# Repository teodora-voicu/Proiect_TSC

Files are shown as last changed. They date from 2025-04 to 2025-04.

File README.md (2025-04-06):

# OpenBook Reader - Teodora-Andreea Voicu

# Hardware Description

**ESP32-C6-WROOM-1-N8 Microcontroller**
- Serves as the central processing unit, managing all communication and control  
- Supports Wi-Fi, Bluetooth, Zigbee, and Thread for wireless communication

**RTC Module (DS3231SN)**
- Maintains accurate timekeeping and provides time/date information via the I2C protocol

**Flash Memory (W25Q512JVEIQ)**
- Provides high-speed storage using the SPI protocol  
- Used for firmware and data storage

**Battery Management IC (MCP73831)**
- Handles charging of the Li-Ion battery with input from the USB Type-C port  
- GPIO pins monitor charging status and control power management

**Fuel Gauge IC (MAX17048G+T10)**
- Tracks the battery's state of charge and communicates with the microcontroller via I2C

**Environmental Sensor (BME680)**
- Monitors temperature, humidity, pressure, and gas levels  
- Connects via the I2C protocol

**ePaper Display**
- Displays information to the user  
- Interfaced using SPI for fast data updates

**SD Card Socket (J4)**
- Provides expandable storage for data logging or firmware updates  
- Communicates using SPI

**USB Type-C Port (J2)**
- Supplies power to the system and enables communication with external devices  
- Includes D+ and D− lines for USB data transfer

# Detailed ESP32-C6 View

**ESP32-C6 Pin Connections**
- **3V3**: Charging 3.3V  
- **EN**: Reset button  
- **IO0**: Communication with the RTC (alert or timing signals)  
- **IO1**: Communication with the RTC for a stable clock reference  
- **IO2**: Used for SPI (Master In Slave Out)  
- **IO3**: Connects to the display, indicating the display’s busy status  
- **IO4**: Communicates with the SD card  
- **IO5**: Connects to the display, distinguishing between data and command signals  
- **IO6**: Used for SPI communication, synchronizes data transfer  
- **IO7**: Used for SPI (Master Out Slave In)  
- **IO8**:  
- **IO9**: Boot button  
- **IO10**: Connects to the display, selects the display for communication  
- **IO11**: Selects the flash memory for communication  
- **IO12**: D+ for USB connection  
- **IO13**: D− for USB connection  
- **IO15**: Change button  
- **TXD0 / GPIO16**: Used for UART debugging  
- **RXD0 / GPIO17**: Used for UART debugging  
- **IO18**: Resets the RTC  
- **IO19**: Power pin for I2C communication  
- **IO20**: Power supply for the display  
- **IO21**: I2C data pin  
- **IO22**: I2C clock pin  
- **IO23**: Resets the display  
- **GND**: Connected to ground

## BOM

| **Piece Name** | **Piece Type (Optional)** | **Link** |
|---|---|---|
| ESP32-CAP C0402 | C | https://componentsearchengine.com/part-view/CC0402MRX5R5BB106/YAGEO |
| ADAFRUIT_CHIP-LED0603 | LED | https://www.snapeda.com/parts/KP-1608SURCK/Kingbright/view-part/?ref=search&t=LED%200603 |
| 112ATAARR03 | microSD | https://www.snapeda.com/parts/112A-TAAR-R03/Attend/view-part/ |
| 744043680 | L | https://eu.mouser.com/ProductDetail/Wurth-Elektronik/744043680?qs=PGXP4M47uW6VkZq%252BkzjrHA%3D%3D |
| BD5229G-TR | Voltage Detector | https://www.snapeda.com/parts/BD5229G-TR/Rohm/view-part/?ref=search&t=BD5229G-TR |
| BUTTON_CUSYOMV1 | Button | https://www.snapeda.com/search/?q=EVQP7L01P&search-type=parts |
| CPH3225A | C | https://www.snapeda.com/parts/CPH3225A/Seiko/view-part/ |
| DS3231SN# | I²C-Integrated RTC/TCXO/Crystal | https://www.snapeda.com/parts/DS3231SN%23/Analog%20Devices/view-part/?ref=search&t=DS3231SN%23 |
| ESP32-C6-WROOM-1-N8 | ESP32 | https://www.snapeda.com/parts/ESP32-C6-WROOM-1-N8/Espressif%20Systems/view-part/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 |
| ESP VARSISTOR | Varsistor (B72520T0350K062) | https://ro.mouser.com/ProductDetail/EPCOS-TDK/B72520T0350K062?qs=dEfas%2FXlABIszF52uu7vrg%3D%3D |
| ESP32_WROVER_AVX---SD0805S020S1R0 |  DIODE SCHOTTKY | https://componentsearchengine.com/part-view/SD0805S020S1R0/Kyocera%20AVX |
| ESP32_WROVER_BME680_BME680 | Env Senzor | https://www.snapeda.com/parts/BME680/Bosch%20Sensortec/view-part/?ref=search&t=bme680 |
| ESP32_WROVER_EAGLE-LTSPICE_R | R | https://componentsearchengine.com/part-view/R0402%201%25%20100%20K%20(RC0402FR-07100KL)/YAGEO |
| ESP32_WROVER_SPARKFUN-DISCRETESEMI_MOSFET_PCH | T DMG2305UX-7 | https://componentsearchengine.com/part-view/DMG2305UX-7/Diodes%20Incorporated |
| ESP32_WROVER_SPARKFUN-IC-POWER_MCP73831 | TINY INTEGRATED LI-ION/LI-POLY CHARGE MGNT CONTROLLER | https://componentsearchengine.com/part-view/MCP73831T-2ACI%2FOT/Microchip |
| FH34SRJ-24S-0.5SH_99_ | FH34SRJ-24S-0.5SH(99) | https://componentsearchengine.com/part-view/FH34SRJ-24S-0.5SH(99)/Hirose |
| MAX17048G+T10 |  Cell Fuel Gauge with ModelGauge | https://www.snapeda.com/parts/MAX17048G+T10/Analog%20Devices/view-part/ |
| MBR0530 |  Diode Schottky | https://www.snapeda.com/parts/MBR0530/Onsemi/view-part/ |
| PGB1010603MR |  Ipp Tvs Diode Surface Mount 0603 | https://www.snapeda.com/parts/PGB1010603MR/Littelfuse/view-part/ |
| QWIIC_CONNECTOR | PRT-14417 QWIIC_CONNECTOR | https://www.snapeda.com/parts/PRT-14417/SparkFun/view-part/ |
| RCL_CPOL-EU | C pol | https://grabcad.com/library/tantalum-smd-capacitor-type-b-3528-1 |
| SAMACSYS_PARTS_USB4110-GF-A | USB4110-GF-A | https://www.snapeda.com/parts/USB4110-GF-A./Global%20Connector%20Technology/view-part/ |
| SJ | Jumper-SolderPasteJumper3way | https://grabcad.com/library/solder-jumpers-1 |
| TP | Test-Pad | - |
| SI1308EDL-T1-GE3 |  MOSFET Transistor | https://www.snapeda.com/parts/SI1308EDL-T1-GE3/Vishay/view-part/ |
| USBLC6-2SC6Y |  Ipp Tvs Diode Surface Mount | https://www.snapeda.com/parts/USBLC6-2SC6Y/STMicroelectronics/view-part/?ref=dk&t=USBLC6-2SC6Y&con_ref=None |
| W25Q512JVEIQ | FLASH - NOR Memory | https://www.snapeda.com/parts/W25Q512JVEIQ/Winbond%20Electronics/view-part/?ref=search&t=W25Q512JVEIQ |
| XC6220A331MR-G | Voltage Regulator | https://ro.mouser.com/ProductDetail/Torex-Semiconductor/XC6220A331MR-G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 |

# Block Diagram
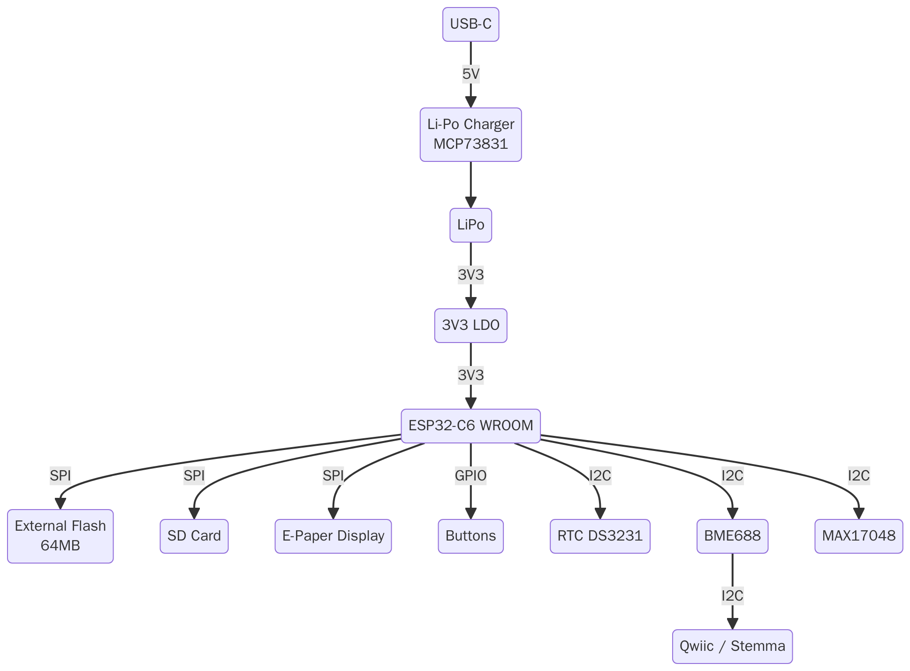
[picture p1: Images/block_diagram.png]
Block Diagram


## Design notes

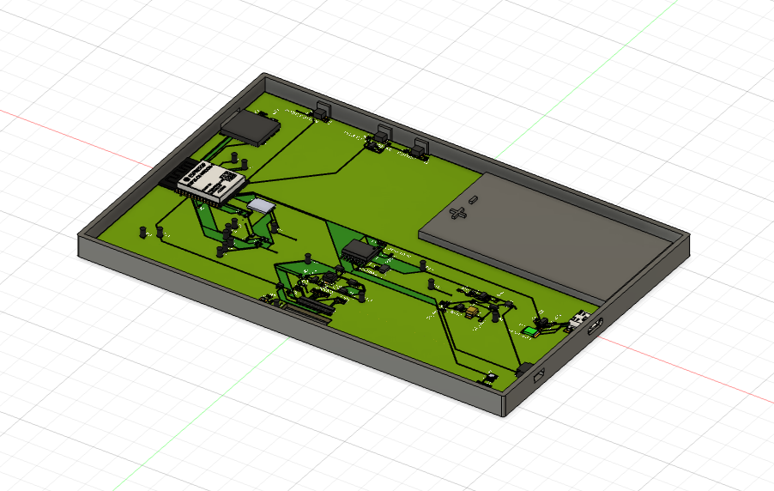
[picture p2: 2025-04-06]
Images/full_home_no_lid.png

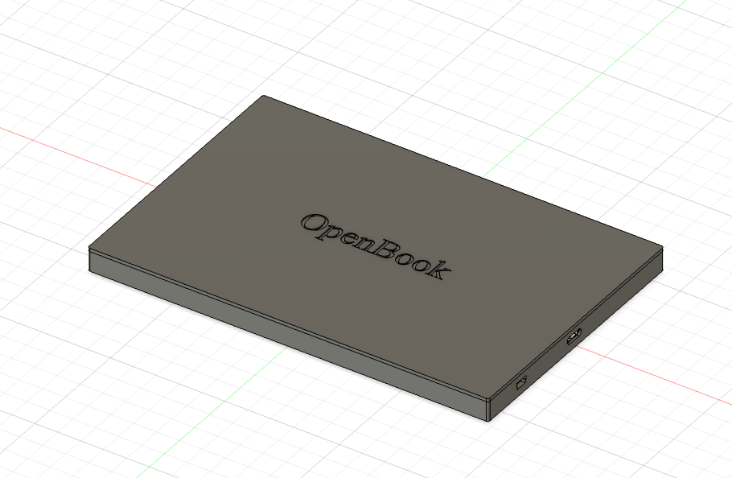
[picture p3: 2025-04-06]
Images/full_home_lid.png

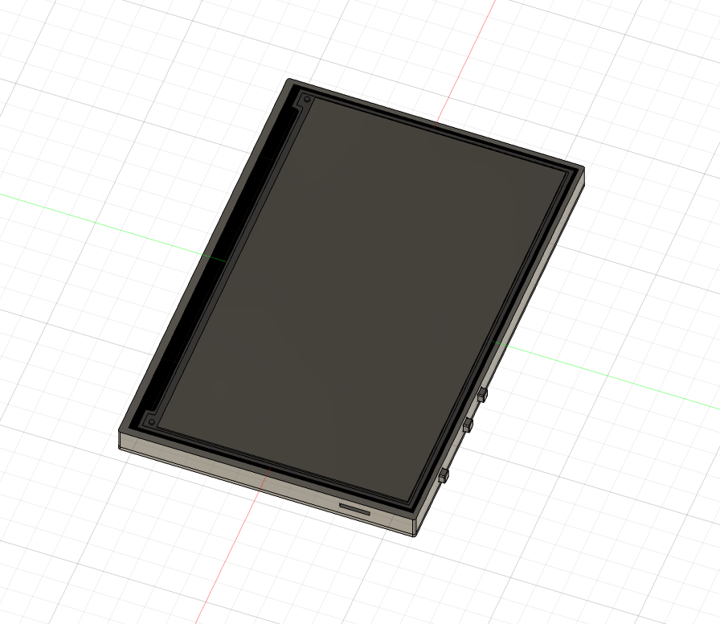
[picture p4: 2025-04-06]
Images/full_top_lid.png

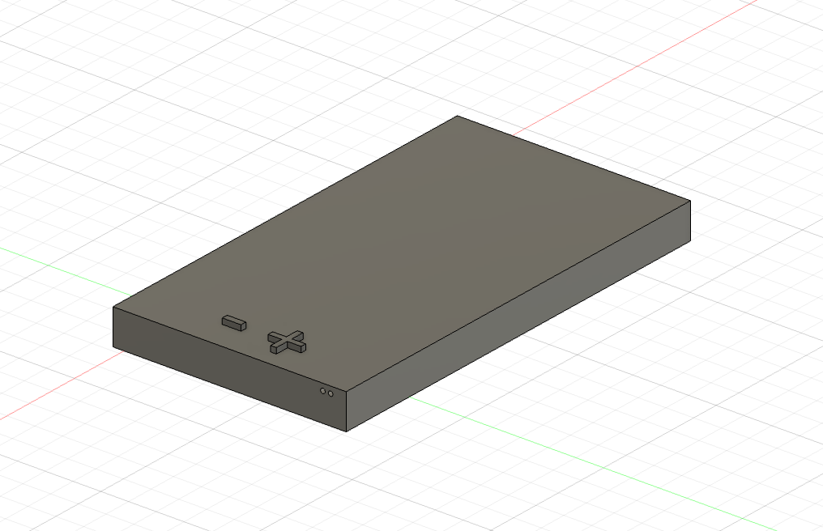
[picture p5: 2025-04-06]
Images/battery.png

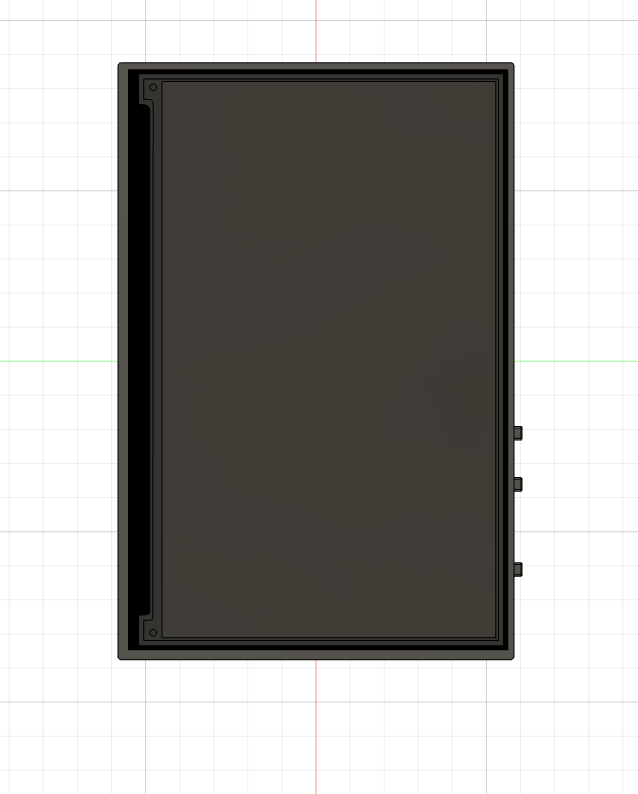
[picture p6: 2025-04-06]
Images/full_top.png

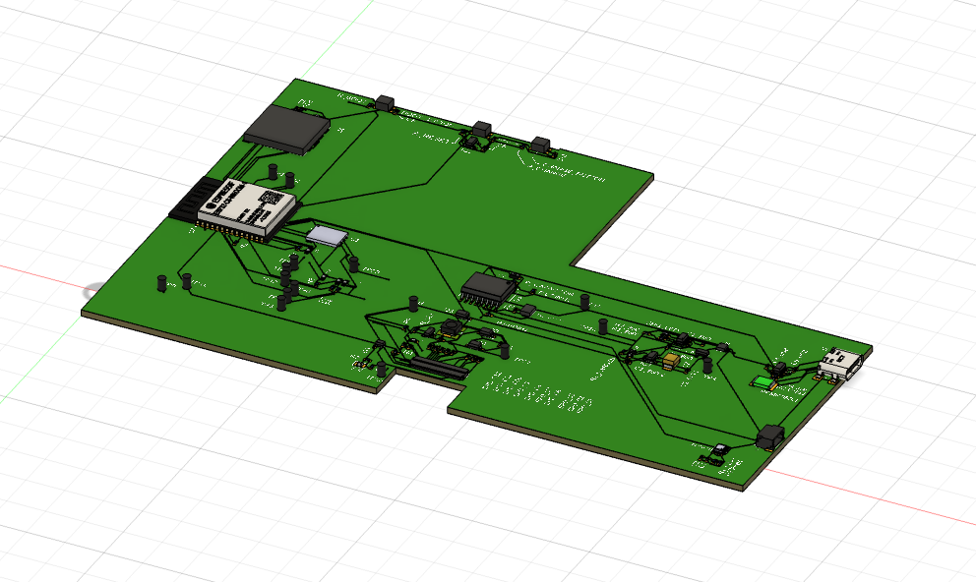
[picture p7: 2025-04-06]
Images/pcb.png

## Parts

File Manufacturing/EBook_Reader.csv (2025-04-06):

Qty | Value | Device | Package | Parts | Description | ARROW_PART_NUMBER | ARROW_PRICE-STOCK | AVAILABILITY | CENTROID_NOT_SPECIFIED | CHECK_PRICES | COPYRIGHT | DATASHEET | DESCRIPTION | DIGIKEY_DESCRIPTION | DIGIKEY_PART_NUMBER | HEIGHT | LEAD_FREE | MANUFACTURER_NAME | MANUFACTURER_PART_NUMBER | MF | MFR_NAME | MOUSER_PART_NUMBER | MOUSER_PRICE-STOCK | MOUSER_TESTING_PART_NUMBER | MOUSER_TESTING_PRICE-STOCK | MP | MPN | PACKAGE | POPULARITY | PREFIX | PRICE | PROD_ID | PURCHASE-URL | ROHS | SNAPEDA_LINK | SPICEMODEL | SPICEPREFIX | TEMPERATURE_RANGE_HIGH | TEMPERATURE_RANGE_LOW | TP_SIGNAL_NAME | VALUE
1 |  | ADAFRUIT_LEDCHIP-LED0603 | ADAFRUIT_CHIP-LED0603 | CHG_LED | LED
1 |  | SJ | SJ | SJ1 | SMD solder JUMPER |  |  |  |  |  |  |  |  |  |  |  |  |  |  |  |  |  |  |  |  |  |  |  | 3
1 | 0.47 | ESP32_WROVER_EAGLE-LTSPICE_RR0402 | ESP32_WROVER_EAGLE-LTSPICE_R0402 | R3 | RESISTOR, European symbol |  |  |  |  |  |  |  |  |  |  |  |  |  |  |  |  |  |  |  |  |  |  |  |  |  |  |  |  |  |  | NONE | R
1 | 100K | ESP32_WROVER_EAGLE-LTSPICE_RR0402 | ESP32_WROVER_EAGLE-LTSPICE_R0402 | R1_PWRUSB | RESISTOR, European symbol |  |  |  |  |  |  |  |  |  |  |  |  |  |  |  |  |  |  |  |  |  |  |  |  |  |  |  |  |  |  | NONE | R
8 | 100nF | ESP32_WROVER_EAGLE-LTSPICE_CC0402 | ESP32_WROVER_EAGLE-LTSPICE_C0402 | C1, C2, C4_USB, C6, C8, C9, C10, C_DELAY | CAPACITOR, European symbol |  |  |  |  |  |  |  |  |  |  |  |  |  |  |  |  |  |  |  |  |  |  |  |  |  |  |  |  |  |  | NONE | C
1 | 100uF TANT | RCL_CPOL-EUCT3528 | RCL_CT3528 | C3 | POLARIZED CAPACITOR, European symbol |  |  |  |  |  |  |  |  |  |  |  |  |  |  |  |  |  |  |  |  |  |  |  | 0 |  |  |  |  |  |  |  | C
14 | 10K | ESP32_WROVER_EAGLE-LTSPICE_RR0402 | ESP32_WROVER_EAGLE-LTSPICE_R0402 | R1, R1-PINH1, R1_PINH, R2-PINH, R2-PINH1, R4, R5, R6, R7, R8, R9, R10, R_BOOT, R_CHANGE | RESISTOR, European symbol |  |  |  |  |  |  |  |  |  |  |  |  |  |  |  |  |  |  |  |  |  |  |  |  |  |  |  |  |  |  | NONE | R
2 | 10k | ESP32_WROVER_EAGLE-LTSPICE_RR0402 | ESP32_WROVER_EAGLE-LTSPICE_R0402 | R_CL1, R_RESET | RESISTOR, European symbol |  |  |  |  |  |  |  |  |  |  |  |  |  |  |  |  |  |  |  |  |  |  |  |  |  |  |  |  |  |  | NONE | R
1 | 10uF | ESP32_WROVER_EAGLE-LTSPICE_CC0402 | ESP32_WROVER_EAGLE-LTSPICE_C0402 | C7 | CAPACITOR, European symbol |  |  |  |  |  |  |  |  |  |  |  |  |  |  |  |  |  |  |  |  |  |  |  |  |  |  |  |  |  |  | NONE | C
1 | 112A-TAAR-R03_ATTEND | 112A-TAAR-R03_ATTEND | 112ATAARR03ATTEND | J4 | Micro SD Card Socket, Push-Push Type, Top Mount, SMT, H=1.83mm, 10u |  |  |  |  |  |  |  | Micro SD Card Socket | Push-Push Type | Top Mount | SMT | H=1.83mm | 10u |  |  | 1.9mm |  | ATTEND | 112A-TAAR-R03 ATTEND
1 | 15 | ESP32_WROVER_EAGLE-LTSPICE_RR0402 | ESP32_WROVER_EAGLE-LTSPICE_R0402 | R_CAPACITOR | RESISTOR, European symbol |  |  |  |  |  |  |  |  |  |  |  |  |  |  |  |  |  |  |  |  |  |  |  |  |  |  |  |  |  |  | NONE | R
1 | 1uF | ESP32_WROVER_EAGLE-LTSPICE_CC0402 | ESP32_WROVER_EAGLE-LTSPICE_C0402 | C5 | CAPACITOR, European symbol |  |  |  |  |  |  |  |  |  |  |  |  |  |  |  |  |  |  |  |  |  |  |  |  |  |  |  |  |  |  | NONE | C
10 | 1uF/50V | ESP32_WROVER_EAGLE-LTSPICE_CC0402 | ESP32_WROVER_EAGLE-LTSPICE_C0402 | EPD_C1, EPD_C2, EPD_C5, EPD_C6, EPD_C7, EPD_C8, EPD_C9, EPD_C10, EPD_C11, EPD_C12 | CAPACITOR, European symbol |  |  |  |  |  |  |  |  |  |  |  |  |  |  |  |  |  |  |  |  |  |  |  |  |  |  |  |  |  |  | NONE | C
1 | 2.2 | ESP32_WROVER_EAGLE-LTSPICE_RR0402 | ESP32_WROVER_EAGLE-LTSPICE_R0402 | R2 | RESISTOR, European symbol |  |  |  |  |  |  |  |  |  |  |  |  |  |  |  |  |  |  |  |  |  |  |  |  |  |  |  |  |  |  | NONE | R
1 | 200 | ESP32_WROVER_EAGLE-LTSPICE_RR0402 | ESP32_WROVER_EAGLE-LTSPICE_R0402 | R1_BAT | RESISTOR, European symbol |  |  |  |  |  |  |  |  |  |  |  |  |  |  |  |  |  |  |  |  |  |  |  |  |  |  |  |  |  |  | NONE | R
2 | 20V/4.2A/52mΩ/1.4W | ESP32_WROVER_SPARKFUN-DISCRETESEMI_MOSFET_PCH-DMG2305UX-7 | ESP32_WROVER_SPARKFUN-DISCRETESEMI_SOT23-3 | Q1, Q2 | P-channel MOSFETs |  |  |  |  |  |  |  |  |  |  |  |  |  |  |  |  |  |  |  |  |  |  |  |  |  |  | TRAN-14388 |  |  |  |  |  |  |  |  | 20V/4.2A/52mΩ/1.4W
1 | 2K | ESP32_WROVER_EAGLE-LTSPICE_RR0402 | ESP32_WROVER_EAGLE-LTSPICE_R0402 | R2_BAT | RESISTOR, European symbol |  |  |  |  |  |  |  |  |  |  |  |  |  |  |  |  |  |  |  |  |  |  |  |  |  |  |  |  |  |  | NONE | R
5 | 4.7uF | ESP32_WROVER_EAGLE-LTSPICE_CC0402 | ESP32_WROVER_EAGLE-LTSPICE_C0402 | C1_BAT, C1_BAT1, C1_BAT2, C2_BAT, C5_USB | CAPACITOR, European symbol |  |  |  |  |  |  |  |  |  |  |  |  |  |  |  |  |  |  |  |  |  |  |  |  |  |  |  |  |  |  | NONE | C
1 | 4.7uF/25V | ESP32_WROVER_EAGLE-LTSPICE_CC0402 | ESP32_WROVER_EAGLE-LTSPICE_C0402 | C4 | CAPACITOR, European symbol |  |  |  |  |  |  |  |  |  |  |  |  |  |  |  |  |  |  |  |  |  |  |  |  |  |  |  |  |  |  | NONE | C
2 | 5k1 | ESP32_WROVER_EAGLE-LTSPICE_RR0402 | ESP32_WROVER_EAGLE-LTSPICE_R0402 | R2-USB, R2-USB1 | RESISTOR, European symbol |  |  |  |  |  |  |  |  |  |  |  |  |  |  |  |  |  |  |  |  |  |  |  |  |  |  |  |  |  |  | NONE | R
1 | 68uH | 744043680IND_4828-WE-TPC_WRE | IND_4828-WE-TPC_WRE | L1 |  |  |  |  |  |  | Copyright (C) 2024 Ultra Librarian. All rights reserved. |  |  |  |  |  |  |  | 744043680 |  | Wurth Electronics
1 | BD5229G-TR | BD5229G-TR | SOT95P280X125-5N | IC1 | Voltage Detector with Adjustable Delay Time: CMOS processes are utilized to develop high precision, low current consumption CMOS reset ICs that allow arbitrary setting of the delay time. The extensive lineup includes both Nch Open Drain and CMOS output types in a wide range of detection voltages (from 2.3V to 6.0V, in 0.1V steps), enabling selection of the ideal solution based on customer requirements. In addition, the entire series is of course both lead-free and RoHS-compliant. |  |  |  |  |  |  |  | Voltage Detector with Adjustable Delay Time: CMOS processes are utilized to develop high precision | low current consumption CMOS reset ICs that allow arbitrary setting of the delay time. The extensive lineup includes both Nch Open Drain and CMOS output types in a wide range of detection voltages (from 2.3V to 6.0V | in 0.1V steps) | enabling selection of the ideal solution based on customer requirements. In addition | the entire series is of course both lead-free and RoHS-compliant. |  |  | 1.25mm |  | ROHM Semiconductor | BD5229G-TR |  |  | 755-BD5229G-TR | https://www.mouser.co.uk/ProductDetail/ROHM-Semiconductor/BD5229G-TR?qs=4kLU8WoGk0vvnhrrYwdszw%3D%3D
3 | BUTTON_CUSYOMV1 | BUTTON_CUSYOMV1 | MYBUTTON | BOOT_BUTTON, CHANGE_BUTTON, RESET_BUTTON
1 | CPH3225A | CPH3225A | CAPCP3225X100N | C10_SUPERCAP | Cap 0.011F 3.3V 1210 Flat Check availability |  |  | Not in stock |  | https://www.snapeda.com/parts/CPH3225A/Seiko+Instruments/view-part/?ref=eda |  |  | 11 mF (EDLC) Supercapacitor 3.3 V 1210 (3225 Metric) - - |  |  |  |  |  |  | Seiko Instruments |  |  |  |  |  | CPH3225A |  | 1210 Seiko |  |  | None |  | https://www.snapeda.com/api/url_track_click_mouser/?unipart_id=562593&manufacturer=Seiko Instruments&part_name=CPH3225A&search_term=None |  | https://www.snapeda.com/parts/CPH3225A/Seiko+Instruments/view-part/?ref=snap
1 | DS3231SN# | DS3231SN# | SOIC127P1032X265-16N | U3 | Real Time Clock Serial 16-Pin SOIC W T/R Check availability |  |  | In Stock |  | https://www.snapeda.com/parts/DS3231SN%23/Analog+Devices/view-part/?ref=eda |  |  | Extremely Accurate I²C-Integrated RTC/TCXO/Crystal |  |  |  |  |  |  | Analog Devices |  |  |  |  |  | DS3231SN# |  | SOIC-16 Maxim |  |  | None |  | https://www.snapeda.com/api/url_track_click_mouser/?unipart_id=99048&manufacturer=Analog Devices&part_name=DS3231SN#&search_term=None |  | https://www.snapeda.com/parts/DS3231SN%23/Analog+Devices/view-part/?ref=snap
1 | ESP32-C6-WROOM-1-N8 | ESP32-C6-WROOM-1-N8 | XCVR_ESP32-C6-WROOM-1-N8 | U2 | Check availability |  |  | In Stock |  | https://www.snapeda.com/parts/ESP32-C6-WROOM-1-N8/Espressif+Systems/view-part/?ref=eda |  |  | Multiprotocol Modules ESP32-C6 module | Wi-Fi 6 in 2.4 GHz band | Bluetooth 5 | Zigbee 3.0 and Thread. ESP34-WROOM Compatible - ENGINEERING SAMPLE |  |  |  |  |  |  | Espressif Systems |  |  |  |  |  | ESP32-C6-WROOM-1-N8 |  | None |  |  | None |  |  |  | https://www.snapeda.com/parts/ESP32-C6-WROOM-1-N8/Espressif+Systems/view-part/?ref=snap
1 | ESP32C6_VARISTORCN1812 | ESP32C6_VARISTORCN1812 | ESP32C6_VARISTOR_CT/CN1812 | PFMF.050.1 | VARISTOR |  |  |  |  |  |  |  |  |  |  |  |  |  |  |  |  |  |  |  |  |  |  |  | 0
2 | ESP32_WROVER_AVX---SD0805S020S1R0_AVX_SD0805S020S1R0_0_0AVX_SD0805S020S1R0_0_0 | ESP32_WROVER_AVX---SD0805S020S1R0_AVX_SD0805S020S1R0_0_0AVX_SD0805S020S1R0_0_0 | ESP32_WROVER_AVX---SD0805S020S1R0_AVX_SD0805S020S1R0_0 | D2, D7 | Schottky Barrier Rectifier Diode |  |  |  | No |  |  | http://datasheets.avx.com/schottky.pdf |  | DIODE SCHOTTKY 20V 1A 0805 | 478-7800-1-ND |  | yes |  |  | AVX |  | 581-SD0805S020S1R0 |  |  |  |  |  | 0805 (2012 metric) |  | D |  |  |  | yes |  |  |  | +125°C | -55°C
1 | ESP32_WROVER_BME680_BME680 | ESP32_WROVER_BME680_BME680 | ESP32_WROVER_BME680_PSON80P300X300X100-8N | SENSOR2 | Integrated Environmental Unit |  |  | Unavailable |  |  |  |  | Integrated Environmental Unit |  |  |  |  |  |  | Bosch Sensortec |  |  |  |  |  | BME680 |  | LGA-8 Bosch Tools |  |  | None
1 | ESP32_WROVER_SPARKFUN-IC-POWER_MCP73831 | ESP32_WROVER_SPARKFUN-IC-POWER_MCP73831 | ESP32_WROVER_SPARKFUN-IC-POWER_SOT23-5 | MCP73831 | MCP73831T Li-Ion, Li-Pol Controller |  |  |  |  |  |  |  |  |  |  |  |  |  |  |  |  |  |  |  |  |  |  |  |  |  |  | IC-09995
1 | FH34SRJ-24S-0.5SH_99_ | FH34SRJ-24S-0.5SH_99_ | FH34SRJ24S05SH99 | J1 | (0.50mm) Surface Mount, Right Angle |  |  |  |  |  |  |  | 24 Position FFC | FPC Connector Contacts | (0.50mm) Surface Mount | Right Angle |  |  | 1.1mm |  | Hirose | FH34SRJ-24S-0.5SH(99) |  |  | 798-FH34SRJ24S05SH99 | https://www.mouser.co.uk/ProductDetail/Hirose-Connector/FH34SRJ-24S-0.5SH99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
1 | MAX17048G+T10 | MAX17048G+T10 | SON50P200X200X80-9N | U4 | Check availability |  |  | In Stock |  | https://www.snapeda.com/parts/MAX17048G+T10/Analog+Devices/view-part/?ref=eda |  |  | 3µA 1-Cell/2-Cell Fuel Gauge with ModelGauge |  |  |  |  |  |  | Analog Devices |  |  |  |  |  | MAX17048G+T10 |  | TDFN-8 Maxim |  |  | None |  | https://www.snapeda.com/api/url_track_click_mouser/?unipart_id=329239&manufacturer=Analog Devices&part_name=MAX17048G+T10&search_term=None |  | https://www.snapeda.com/parts/MAX17048G+T10/Analog+Devices/view-part/?ref=snap
3 | MBR0530 | MBR0530 | SOD3716X135N | D3, D4, D5 | ON SEMICONDUCTOR - MBR0530 - DIODE, SCHOTTKY, 0.5A, 30V, SOD-123 |  |  | In Stock |  | https://www.snapeda.com/parts/MBR0530/Onsemi/view-part/?ref=eda |  |  | Diode Schottky 30 V 500mA Surface Mount SOD-123 |  |  |  |  |  |  | ON Semiconductor |  |  |  |  |  | MBR0530 |  | SOD-123-2 ON Semiconductor |  |  | None |  | https://www.snapeda.com/api/url_track_click_mouser/?unipart_id=179458&manufacturer=ON Semiconductor&part_name=MBR0530&search_term=None |  | https://www.snapeda.com/parts/MBR0530/Onsemi/view-part/?ref=snap
6 | PGB1010603MR | PGB1010603MR | DIOC1608X36N | D6, D8, D9, D10, D11, D12 | Check availability |  |  | In Stock |  | https://www.snapeda.com/parts/PGB1010603MR/Littelfuse/view-part/?ref=eda |  |  | 150V (Typ) Clamp - Ipp Tvs Diode Surface Mount 0603 (1608 Metric) |  |  |  |  |  |  | Littelfuse Inc. |  |  |  |  |  | PGB1010603MR |  | 0603 Littelfuse Inc. |  |  | None |  | https://www.snapeda.com/api/url_track_click_mouser/?unipart_id=5659453&manufacturer=Littelfuse Inc.&part_name=PGB1010603MR&search_term=None |  | https://www.snapeda.com/parts/PGB1010603MR/Littelfuse/view-part/?ref=snap
1 | QWIIC_RIGHT_ANGLE | QWIIC_CONNECTORJS-1MM | JST04_1MM_RA | J3 | SparkFun I2C Standard Qwiic Connector |  |  |  |  |  |  |  |  |  |  |  |  |  |  |  |  |  |  |  |  |  |  |  |  |  |  | CONN-13694 |  |  |  |  |  |  |  |  | QWIIC_RIGHT_ANGLE
1 | SAMACSYS_PARTS_USB4110-GF-A | SAMACSYS_PARTS_USB4110-GF-A | SAMACSYS_PARTS_USB4110GFA | J2 | CONN USB 2.0 TYPE-C R/A SMT |  |  |  |  |  |  |  | CONN USB 2.0 TYPE-C R/A SMT |  |  | 3.26mm |  | GCT (GLOBAL CONNECTOR TECHNOLOGY) | USB4110-GF-A |  |  | 640-USB4110-GF-A | https://www.mouser.co.uk/ProductDetail/GCT/USB4110-GF-A?qs=KUoIvG%2F9IlYiZvIXQjyJeA%3D%3D
1 | SI1308EDL-T1-GE3 | SI1308EDL-T1-GE3 | SOT65P210X110-3N | Q3 | MOSFET N-Ch 30V 1.5A TrenchFET SC70 Vishay Si1308EDL-T1-GE3 N-channel MOSFET Transistor, 1.5 A, 30 V, 3-Pin SC-70 |  |  | In Stock |  | https://www.snapeda.com/parts/SI1308EDL-T1-GE3/Vishay+Siliconix/view-part/?ref=eda |  |  | Si1308EDL-T1-GE3 N-channel MOSFET Transistor | 1.5 A | 30 V | 3-Pin SC-70 | Siliconix / Vishay SI1308EDL-T1-GE3 |  |  |  |  |  |  | Vishay Siliconix |  |  |  |  |  | SI1308EDL-T1-GE3 |  | SOT-323 Vishay Semiconductor |  |  | None |  | https://www.snapeda.com/api/url_track_click_mouser/?unipart_id=274603&manufacturer=Vishay Siliconix&part_name=SI1308EDL-T1-GE3&search_term=None |  | https://www.snapeda.com/parts/SI1308EDL-T1-GE3/Vishay+Siliconix/view-part/?ref=snap
17 | TPTP20R | TPTP20R | TP20R | TP1, TP2, TP3, TP4, TP5, TP6, TP7, TP8, TP9, TP10, TP11, TP12, TP13, TP14, TP15, TP16, TP17 | Test pad |  |  |  |  |  |  |  |  |  |  |  |  |  |  |  |  |  |  |  |  |  |  |  | 2
1 | USBLC6-2SC6Y | USBLC6-2SC6Y | SOT95P280X145-6N | D1 | Low Cap. ESD Protection Auto SOT-23-6 STMicroelectronics USBLC6-2SC6Y, Dual Uni-Directional TVS Diode Array, 6-Pin SOT-23 |  |  | In Stock |  | https://www.snapeda.com/parts/USBLC6-2SC6Y/STMicroelectronics/view-part/?ref=eda |  |  | 17V Clamp 5A (8/20µs) Ipp Tvs Diode Surface Mount SOT-23-6 |  |  |  |  |  |  | STMicroelectronics |  |  |  |  |  | USBLC6-2SC6Y |  | SOT-23-6 STMicroelectronics |  |  | None |  |  |  | https://www.snapeda.com/parts/USBLC6-2SC6Y/STMicroelectronics/view-part/?ref=snap
1 | W25Q512JVEIQ | W25Q512JVEIQ | SON127P600X800X80-9N | U1 | Check availability |  |  | In Stock |  | https://www.snapeda.com/parts/W25Q512JVEIQ/Winbond+Electronics/view-part/?ref=eda |  |  | FLASH - NOR Memory IC 512Mb (64M x 8) SPI - Quad I/O 133 MHz 8-WSON (8x6) |  |  |  |  |  |  | Winbond Electronics |  |  |  |  |  | W25Q512JVEIQ |  | Package |  |  | None |  |  |  | https://www.snapeda.com/parts/W25Q512JVEIQ/Winbond+Electronics/view-part/?ref=snap
1 | XC6220A331MR-G | XC6220A331MR-G | SOT95P280X120-5N | IC4 | LDO Voltage Regulators |  |  |  |  |  |  |  | LDO Voltage Regulators |  |  | 1.2mm |  | Torex | XC6220A331MR-G |  |  | 865-XC6220A331MR-G | https://www.mouser.co.uk/ProductDetail/Torex-Semiconductor/XC6220A331MR-G?qs=AsjdqWjXhJ8ZSWznL1J0gg%3D%3D

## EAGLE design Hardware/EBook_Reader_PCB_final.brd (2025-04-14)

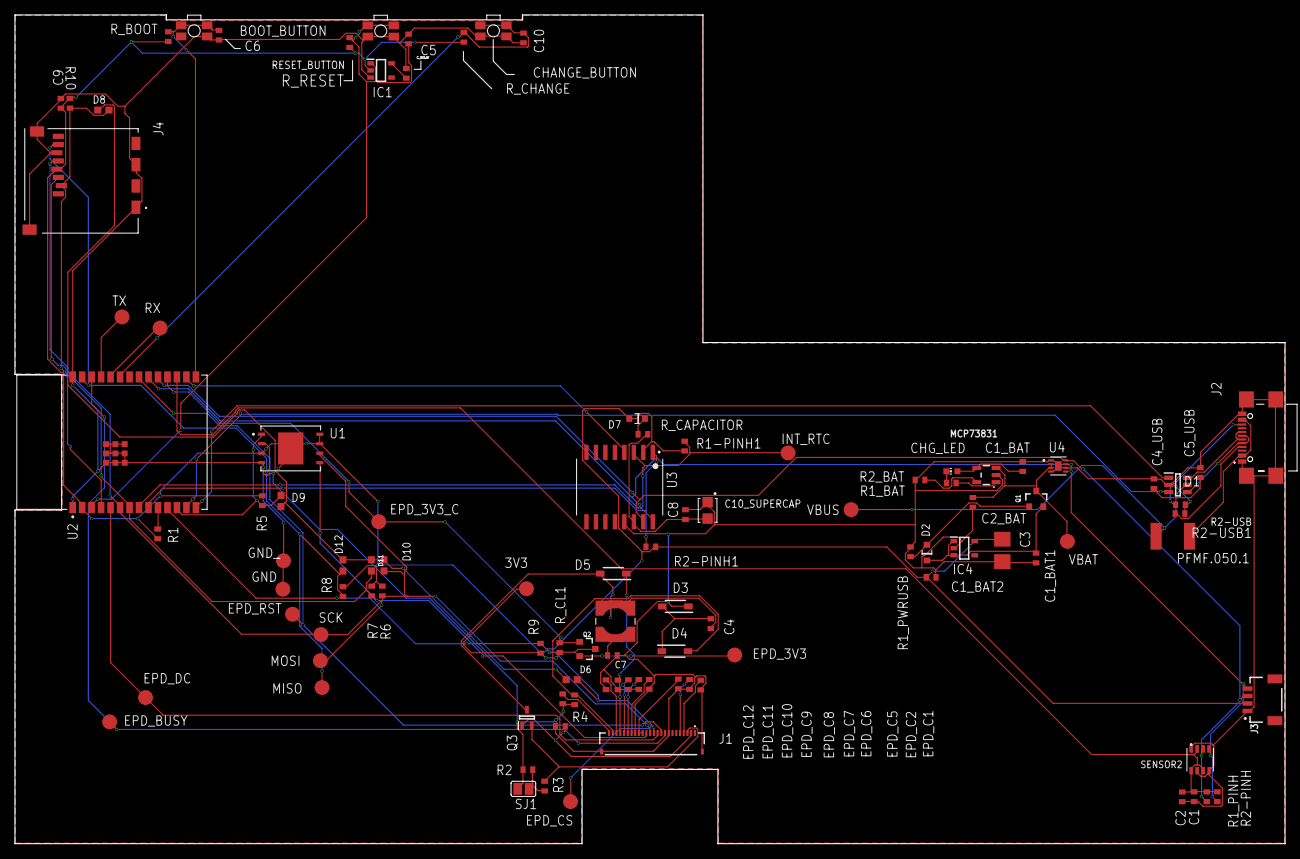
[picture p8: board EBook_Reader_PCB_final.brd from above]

Board: 2 copper layers, 170.2 x 111.1 mm, 103 parts (0 on the bottom side), 61 nets.

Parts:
3V3: TPTP20R; TP20R
BOOT_BUTTON: BUTTON_CUSYOMV1; MYBUTTON
C1, C2, C4_USB, C6, C8, C9, C10: 100nF; ESP32_WROVER_EAGLE-LTSPICE_C0402
C1_BAT, C1_BAT1, C1_BAT2, C2_BAT, C5_USB: 4.7uF; ESP32_WROVER_EAGLE-LTSPICE_C0402
C3: 100uF TANT; RCL_CT3528
C4: 4.7uF/25V; ESP32_WROVER_EAGLE-LTSPICE_C0402
C5: 1uF; ESP32_WROVER_EAGLE-LTSPICE_C0402
C7: 10uF; ESP32_WROVER_EAGLE-LTSPICE_C0402
C10_SUPERCAP: CPH3225A; CAPCP3225X100N
CHANGE_BUTTON: BUTTON_CUSYOMV1; MYBUTTON
CHG_LED: ADAFRUIT_CHIP-LED0603
C_DELAY: 100nF; ESP32_WROVER_EAGLE-LTSPICE_C0402
D1: USBLC6-2SC6Y; SOT95P280X145-6N
D2, D7: ESP32_WROVER_AVX---SD0805S020S1R0_AVX_SD0805S020S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; ESP32_WROVER_AVX---SD0805S020S1R0_AVX_SD0805S020S1R0_0
D3, D4, D5: MBR0530; SOD3716X135N
D6, D8, D9, D10, D11, D12: PGB1010603MR; DIOC1608X36N
EPD_3V3, EPD_3V3_C: TPTP20R; TP20R
EPD_BUSY: TPTP20R; TP20R
EPD_C1, EPD_C2, EPD_C5, EPD_C6, EPD_C7, EPD_C8, EPD_C9, EPD_C10, EPD_C11, EPD_C12: 1uF/50V; ESP32_WROVER_EAGLE-LTSPICE_C0402
EPD_CS: TPTP20R; TP20R
EPD_DC: TPTP20R; TP20R
EPD_RST: TPTP20R; TP20R
GND: TPTP20R; TP20R
GND_: TPTP20R; TP20R
IC1: BD5229G-TR; SOT95P280X125-5N
IC4: XC6220A331MR-G; SOT95P280X120-5N
INT_RTC: TPTP20R; TP20R
J1: FH34SRJ-24S-0.5SH_99_; FH34SRJ24S05SH99
J2: SAMACSYS_PARTS_USB4110-GF-A; SAMACSYS_PARTS_USB4110GFA
J3: QWIIC_RIGHT_ANGLE; JST04_1MM_RA
J4: 112A-TAAR-R03_ATTEND; 112ATAARR03ATTEND
L1: 68uH; IND_4828-WE-TPC_WRE
MCP73831: ESP32_WROVER_SPARKFUN-IC-POWER_MCP73831; ESP32_WROVER_SPARKFUN-IC-POWER_SOT23-5
MISO: TPTP20R; TP20R
MOSI: TPTP20R; TP20R
PFMF.050.1: ESP32C6_VARISTORCN1812; ESP32C6_VARISTOR_CT/CN1812
Q1, Q2: 20V/4.2A/52mΩ/1.4W; ESP32_WROVER_SPARKFUN-DISCRETESEMI_SOT23-3
Q3: SI1308EDL-T1-GE3; SOT65P210X110-3N
R1, R1-PINH1, R1_PINH, R2-PINH, R2-PINH1, R4, R5, R6, R7, R8, R9, R10: 10K; ESP32_WROVER_EAGLE-LTSPICE_R0402
R1_BAT: 200; ESP32_WROVER_EAGLE-LTSPICE_R0402
R1_PWRUSB: 100K; ESP32_WROVER_EAGLE-LTSPICE_R0402
R2: 2.2; ESP32_WROVER_EAGLE-LTSPICE_R0402
R2-USB, R2-USB1: 5k1; ESP32_WROVER_EAGLE-LTSPICE_R0402
R2_BAT: 2K; ESP32_WROVER_EAGLE-LTSPICE_R0402
R3: 0.47; ESP32_WROVER_EAGLE-LTSPICE_R0402
RESET_BUTTON: BUTTON_CUSYOMV1; MYBUTTON
RX: TPTP20R; TP20R
R_BOOT: 10K; ESP32_WROVER_EAGLE-LTSPICE_R0402
R_CAPACITOR: 15; ESP32_WROVER_EAGLE-LTSPICE_R0402
R_CHANGE: 10K; ESP32_WROVER_EAGLE-LTSPICE_R0402
R_CL1: 10k; ESP32_WROVER_EAGLE-LTSPICE_R0402
R_RESET: 10k; ESP32_WROVER_EAGLE-LTSPICE_R0402
SCK: TPTP20R; TP20R
SENSOR2: ESP32_WROVER_BME680_BME680; ESP32_WROVER_BME680_PSON80P300X300X100-8N
SJ1: SJ
TX: TPTP20R; TP20R
U1: W25Q512JVEIQ; SON127P600X800X80-9N
U2: ESP32-C6-WROOM-1-N8; XCVR_ESP32-C6-WROOM-1-N8
U3: DS3231SN#; SOIC127P1032X265-16N
U4: MAX17048G+T10; SON50P200X200X80-9N
VBAT: TPTP20R; TP20R
VBUS: TPTP20R; TP20R

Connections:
3V3: 3V3.TP, C1_BAT2.1, C3.+, C9.1, D7.2, IC1.2, IC4.5, J3.2, J4.P4, Q2.3, R1.2, R1-PINH1.2, R2-PINH1.2, R5.2, R6.2, R7.2, R8.2, R9.2, R10.2, R_BOOT.1, R_CHANGE.1, R_CL1.2, R_RESET.1, U1.3, U1.7, U1.8, U2.2, U3.2
32KHZ: R2-PINH1.1, U2.9, U3.1
DN: D1.4, J2.A7, J2.B7
DP: D1.6, J2.A6, J2.B6
EPD_3V3: EPD_3V3.TP, Q2.2
EPD_3V3_C: EPD_3V3_C.TP, Q2.1, R_CL1.1, U2.18
EPD_BUSY: EPD_BUSY.TP, J1.9, U2.26
EPD_CS: D6.2, EPD_CS.TP, J1.12, R9.1, U2.11
EPD_DC: EPD_DC.TP, J1.11, U2.5
EPD_RST: EPD_RST.TP, J1.10, U2.21
FLASH_CS: D9.2, R5.1, U1.1, U2.12
GDR: J1.2, Q3.1, R4.2
GND: BOOT_BUTTON.2, C1.2, C1_BAT.2, C1_BAT1.2, C1_BAT2.2, C2.2, C2_BAT.2, C3.-, C4_USB.2, C5.2, C5_USB.2, C6.2, C7.2, C8.2, C9.2, C10.2, C10_SUPERCAP.1, CHANGE_BUTTON.1, CHANGE_BUTTON.2, C_DELAY.2, D1.2, D3.1, EPD_C1.2, EPD_C2.2, EPD_C5.2, EPD_C6.2, EPD_C7.2, EPD_C8.2, EPD_C9.2, EPD_C10.2, EPD_C11.2, EPD_C12.2, GND.TP, GND_.TP, IC1.3, IC4.2, J1.8, J1.17, J1.MP1, J1.MP2, J2.A1, J2.A12, J2.B1, J2.B12, J2.MP1, J2.MP2, J2.MP3, J2.MP4, J3.1, J4.G1, J4.G2, J4.G3, J4.G4, J4.P6, MCP73831.2, R1_PWRUSB.1, R2.1, R2-USB.2, R2-USB1.1, R2_BAT.1, R4.1, RESET_BUTTON.1, RESET_BUTTON.2, SENSOR2.1, SENSOR2.5, SENSOR2.7, SJ1.1, U1.4, U1.9, U2.1, U2.28, U2.29_1, U2.29_2, U2.29_3, U2.29_4, U2.29_5, U2.29_6, U2.29_7, U2.29_8, U2.29_9, U3.13, U4.1, U4.4, U4.6, U4.9
GND1: D6.1, D8.1, D9.1, D10.1, D11.1, D12.1
GPIO8: R1.1, U2.10
I2C_PW: C1.1, C2.1, R1_PINH.2, R2-PINH.2, SENSOR2.2, SENSOR2.6, SENSOR2.8, U2.17
INT_RTC: INT_RTC.TP, R1-PINH1.1, U2.8, U3.3
IO/BOOT: BOOT_BUTTON.3, BOOT_BUTTON.4, C6.1, R_BOOT.2, U2.15
IO/CHANGE: C10.1, CHANGE_BUTTON.3, CHANGE_BUTTON.4, R_CHANGE.2, U2.23
MISO: D12.2, J4.P7, MISO.TP, R8.1, U1.2, U2.27
MOSI: D11.2, J1.14, J4.P3, MOSI.TP, R7.1, U1.5, U2.7
unnamed: J2.B5, R2-USB.1
unnamed: EPD_C2.1, J1.5
unnamed: EPD_C1.1, J1.4
unnamed: J2.A5, R2-USB1.2
unnamed: C_DELAY.1, IC1.5
unnamed: D7.1, R_CAPACITOR.1
unnamed: C4_USB.1, C5_USB.1
unnamed: D2.2, Q1.1, R1_PWRUSB.2
unnamed: C1_BAT1.1, D2.1, IC4.1, IC4.3, Q1.2
unnamed: C7.1, L1.2
unnamed: C4.1, D3.2, D4.1
unnamed: C1_BAT.1, CHG_LED.A, MCP73831.4
unnamed: CHG_LED.C, R1_BAT.1
unnamed: MCP73831.1, R1_BAT.2
unnamed: MCP73831.5, R2_BAT.2
unnamed: EPD_C12.1, J1.24
unnamed: EPD_C10.1, J1.22
unnamed: EPD_C8.1, J1.20
unnamed: EPD_C7.1, J1.19
unnamed: EPD_C6.1, J1.18
unnamed: EPD_C5.1, J1.15, J1.16
PREVGH: D5.1, EPD_C9.1, J1.21
PREVGL: D4.2, EPD_C11.1, J1.23
RESE: J1.3, Q3.2, R3.2
RESE': R2.2, R3.1, SJ1.2
RESET: C5.1, IC1.1, RESET_BUTTON.3, RESET_BUTTON.4, R_RESET.2, U2.3
RTC_RST: U2.16, U3.4
RX: RX.TP, U2.24
SCK: D10.2, J1.13, J4.P5, R6.1, SCK.TP, U1.6, U2.6
SCL: J3.4, R2-PINH.1, SENSOR2.4, U2.20, U3.16, U4.7
SDA: J3.3, R1_PINH.1, SENSOR2.3, U2.19, U3.15, U4.8
SRC: C4.2, D5.2, L1.1, Q3.3
SS_SD: D8.2, J4.P2, R10.1, U2.4
TX: TX.TP, U2.25
USB_D+: D1.1, U2.14
USB_D-: D1.3, U2.13
VBAT: C2_BAT.1, MCP73831.3, Q1.3, U4.2, U4.3, VBAT.TP
VBUS: D1.5, PFMF.050.1.2, VBUS.TP
VRTC: C8.1, C10_SUPERCAP.2, R_CAPACITOR.2, U3.14
VUSB: J2.A4, J2.A9, J2.B4, J2.B9, PFMF.050.1.1

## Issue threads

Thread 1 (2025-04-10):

Ground planes not fully covering PCB area

emanuelstiuj, 2025-04-10:
**Description:**
The ground planes on both the top and bottom layers do not fully cover the PCB. There are several uncovered areas scattered across the board.

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

**Impact:**
This can result in inconsistent grounding and increased susceptibility to EMI, particularly in sensitive or high-frequency sections of the circuit.

**Suggestion:**
Try disabling the Remove Orphans option when generating copper pours. This can help retain small isolated copper areas that contribute to better coverage.

1. Right-click the edge of the ground pour and select **Properties**.

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

2. Enable the **Orphans** checkbox.

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

Closed 2025-04-11.

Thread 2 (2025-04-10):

PCB thickness should be 1 mm instead of 1.6 mm

emanuelstiuj, 2025-04-10:
**Description:**
The current PCB thickness is set to 1.6 mm, but according to the project requirements, it should be 1.0 mm.

**Impact:**
A thicker PCB might not fit in the enclosure or might conflict with mechanical tolerances in the final assembly.

**Suggestion:**
1. Go to **Rules** → **Preferences** → **Layer Stack**:

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

2. Change the thickness from **1.6 mm** to **1.0 mm**:

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

Closed 2025-04-11.

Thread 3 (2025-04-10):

Test pads should be labeled with signal names

emanuelstiuj, 2025-04-10:
**Description:**
Currently, test pads are labeled with generic names like TP1, TP2, etc. Instead, they should be clearly marked in the silkscreen with the actual signal names they carry (e.g. MISO, MOSI, RX, GND).

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

**Impact:**
Generic labels make debugging and testing harder, especially for people unfamiliar with the board. Clear signal labels improve usability, serviceability, and reduce the chance of probing errors.

**Suggestion:**
1. Right-click on each test pad and go to **Properties**:
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

2. Change the name to match the corresponding signal.
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

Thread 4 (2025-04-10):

Trace widths not following design requirements

emanuelstiuj, 2025-04-10:
**Description:**
According to the design rules, power traces such as VCC, VUSB, VBUS, 3V3, etc. must be routed with a width of 0.3 mm.
Data signal traces must have a minimum width of 0.15 mm.
The current layout does not respect these constraints.

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

**Suggestions:**
1. Go to **Design Manager** → **Signals** → **Power** Signals → **Edit NetClass**

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

2. Make sure all power signals are assigned to the **Power** net class and click **Save**

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

3. Reroute affected traces using the updated rules

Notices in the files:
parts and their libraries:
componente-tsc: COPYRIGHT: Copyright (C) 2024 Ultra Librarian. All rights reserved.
